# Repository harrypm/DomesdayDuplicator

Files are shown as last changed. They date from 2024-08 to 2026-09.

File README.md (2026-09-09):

# Domesday Duplicator (DdD)

Please see the [Project Wiki](https://github.com/harrypm/DomesdayDuplicator/wiki) for details of the project and for access to the project documentation.



The Domesday Duplicator is a LaserDisc capture focused, USB 3.0 based DAQ capable of 40 million samples per second acquisition of analogue RF data at 10-bits resolution, the data being in generic PCM style stream format is ready for real-time FLAC compression via capture apps.

Capturing is easy to use & inspect via the universal (hardware and platform support) [MISRC GUI](https://github.com/harrypm/MISRC-GUI)



# The Decode Family

The samples the DdD capture can be used with the family of decoders that make the FM RF Archival workflow ready to use today.

[LaserDisc Decode](https://github.com/happycube/ld-decode) / [VHS-Decode (Videotape)](https://github.com/oyvindln/vhs-decode/wiki/HiFi-Decode) / [HiFi Decode](https://github.com/oyvindln/vhs-decode/wiki/HiFi-Decode)

# 3D Printed Case 

The Domesday Duplicator also has a [3D models](https://github.com/simoninns/DomesdayDuplicator-Case) and ready to use data for producing 3D printed cases, to protect from dust or line with copper tape for affordable EMI shielding for example.

ddd-case

## Authors

Domesday Duplicator was written & designed by [Simon Inns](https://github.com/simoninns).

Current documentation & fabrication is maintained by [Harry Munday](https://github.com/harrypm). 

## Licences

- [Software License - (Creative Commons BY-SA 4.0)](https://github.com/simoninns/DomesdayDuplicator/blob/master/LICENSE)
- [Hardware License - (GPLv3)](https://creativecommons.org/licenses/by-sa/4.0/)

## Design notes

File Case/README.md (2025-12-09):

# Introduction

This repository contains a 3D printable case design for the Domesday Duplicator.

The case is designed using OpenSCAD and full source code is included.  There are also ready-made STL files for the various parts and materials if you don't want to build them yourself in OpenSCAD.

The case design contains multiple materials however you can easily remix the design using OpenSCAD customization GUI if you wish to print in a single material only (simply deselect the 'fill out text' and 'add logo' options and re-render).  Ready-made single material STL files are also included.



# Printing instructions

## Overview

The model has been printed and tested on the Prusa MK3S/MMU2S printer. All parts fit on a 20x20 printing bed.

The OpenSCAD source files provide a parameter interface that allows you to render either the whole model or the individual parts (ready for STL (or other 3D format) export).  This requires OpenSCAD 2019.05 or later.

## Recommended Print Settings

- Material: PLA Blue and PLA White
- Layer: 0.20mm (Quality)
- Infill: 15%
- Supports: None
- Notes: The upper and lower case parts simply snap together.  4x M3 6mm screws are required to hold the electronics in place.

## Print Time

Clearly this depends on your printer and it's settings.  For the 2 colour multi-material print the time was 11h 15m for both the upper and lower case.  For single-material printing to time was 8h 30m.

## Notes

The design also includes approximate renderings of the FPGA board, the DdD board and the USB3 board.  These are to assist with the design process and are not intended for printing.



# Author

The DomesdayDuplicator case is designed and maintained by Simon Inns.

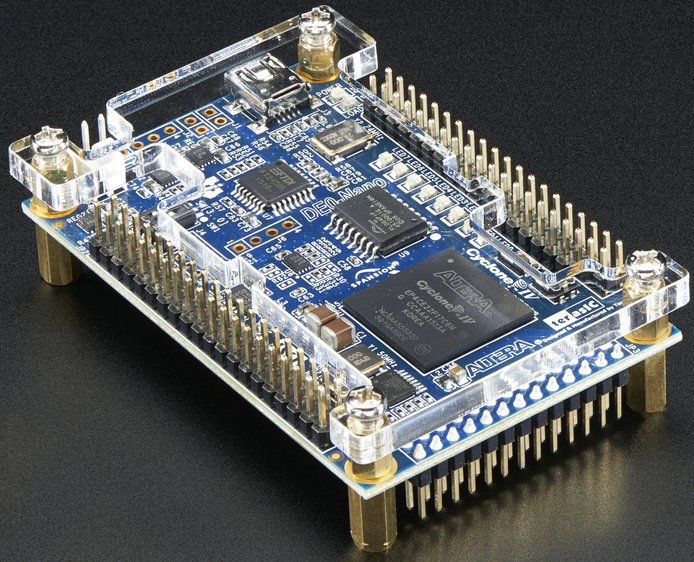
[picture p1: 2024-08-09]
assets/images/DE0.jpg

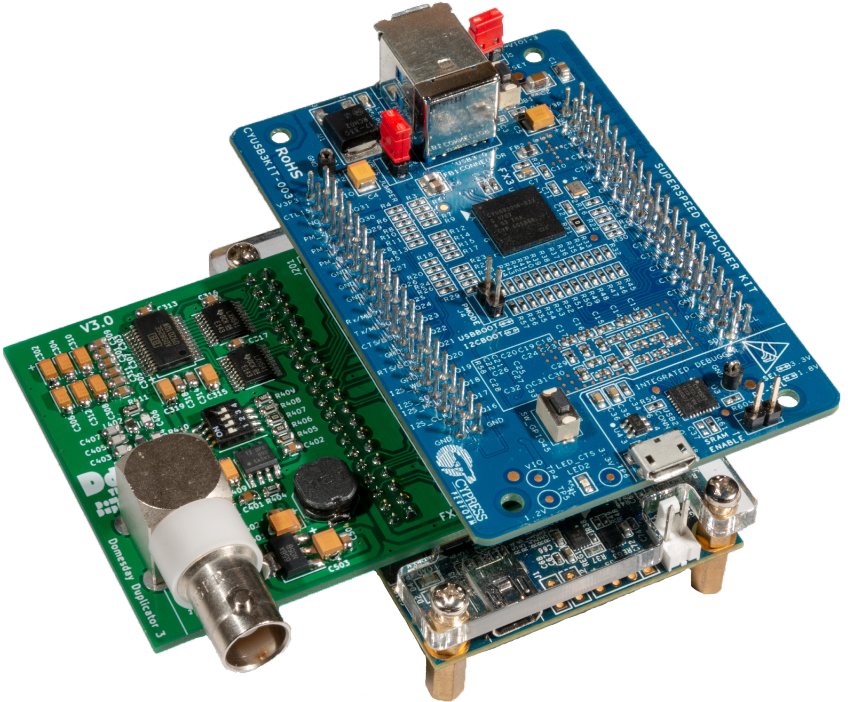
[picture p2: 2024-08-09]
assets/images/DdD-Green-PCB.png

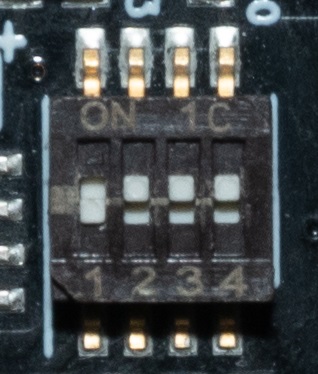
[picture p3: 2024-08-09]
assets/images/Gain_DIPS.jpg

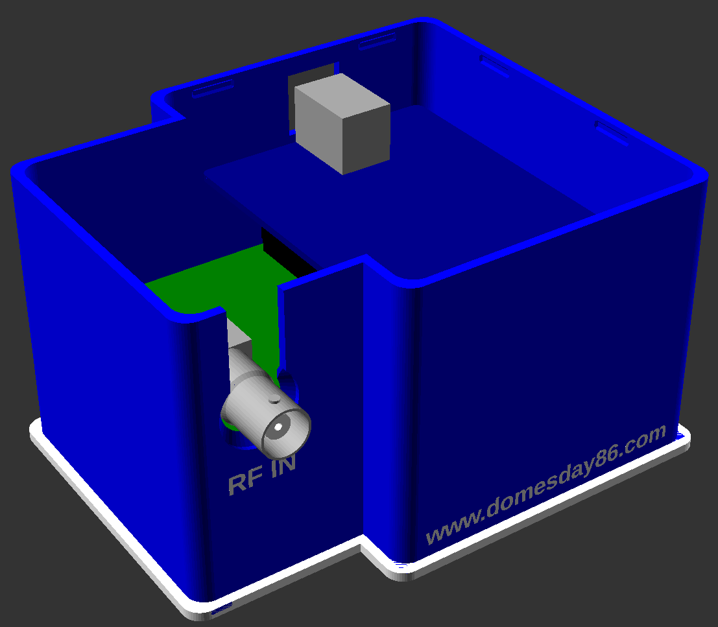
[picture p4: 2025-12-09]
Case/images/DdD-case2.png

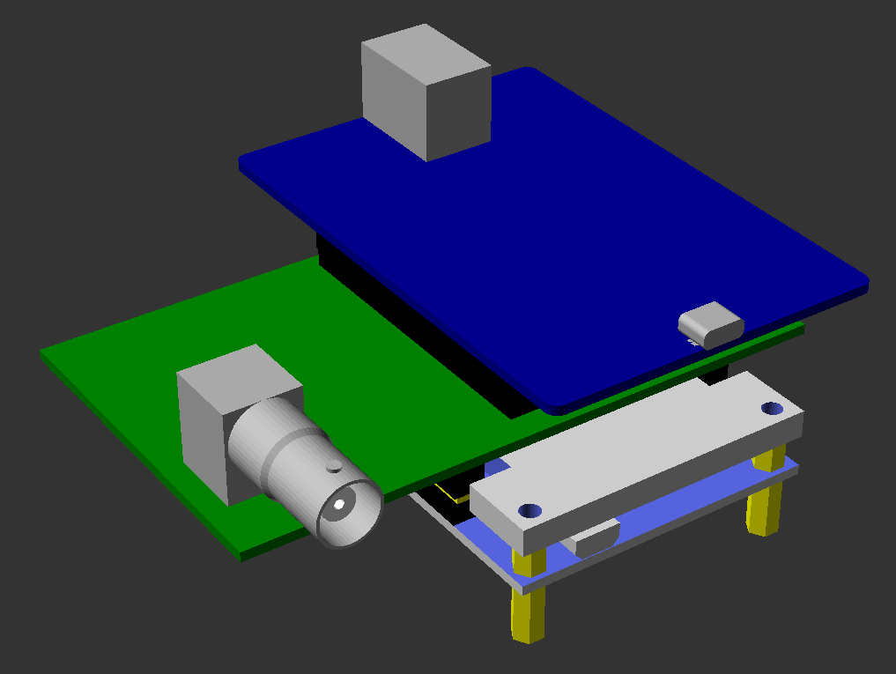
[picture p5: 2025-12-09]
Case/images/DdD-case3.png

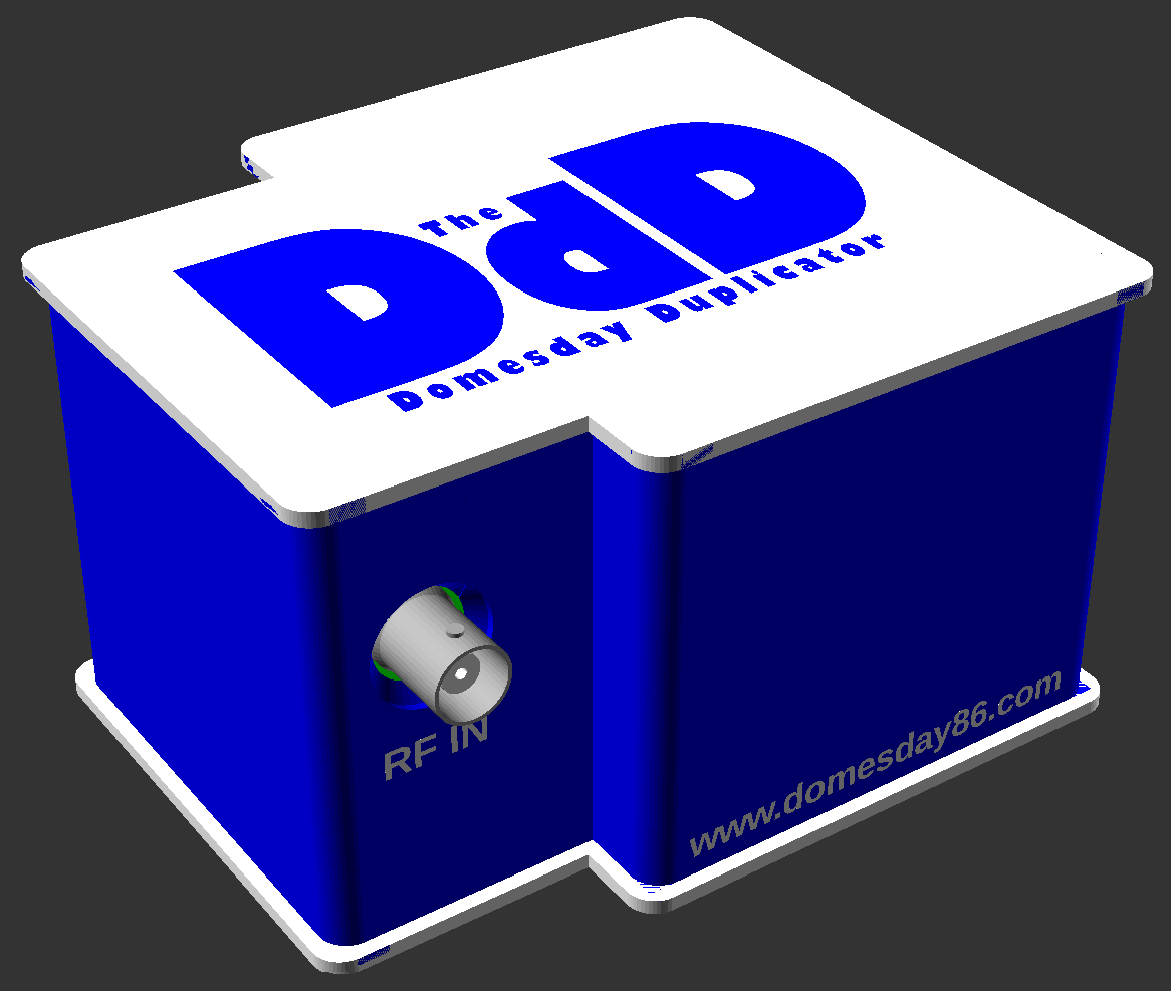
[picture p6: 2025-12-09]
Case/images/DdD-case1.png

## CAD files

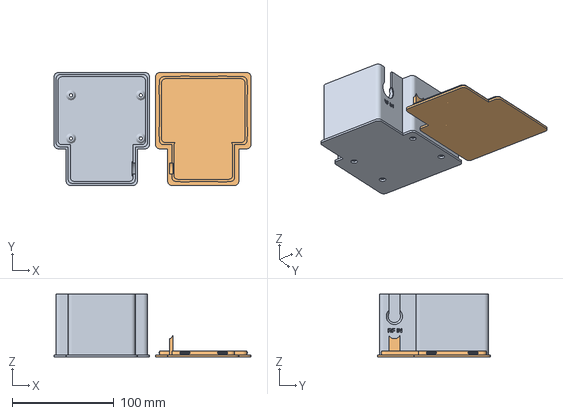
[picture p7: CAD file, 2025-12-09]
Case/3mf/multi_material.3mf
193.9 x 111.0 x 62.0 mm
base_material1.stl
top_material1.stl

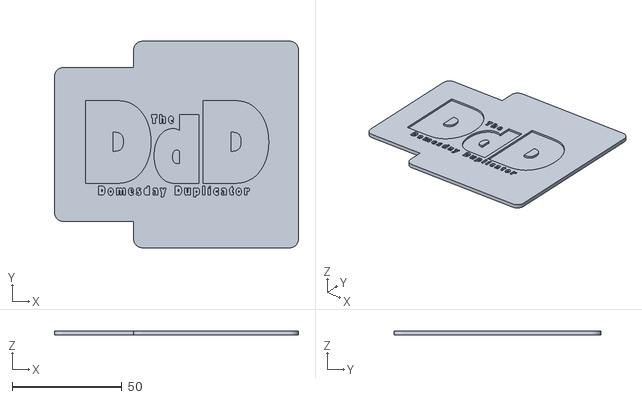
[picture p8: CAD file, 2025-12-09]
Case/stl/top_material1.stl
111.0 x 94.0 x 2.00

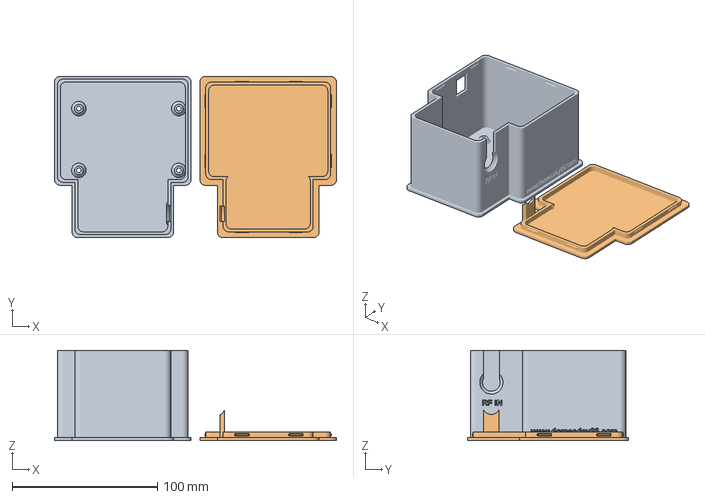
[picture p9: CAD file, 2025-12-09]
Case/3mf/single_material.3mf
194.0 x 111.1 x 62.0 mm
single_material_base.stl
single_material_top.stl

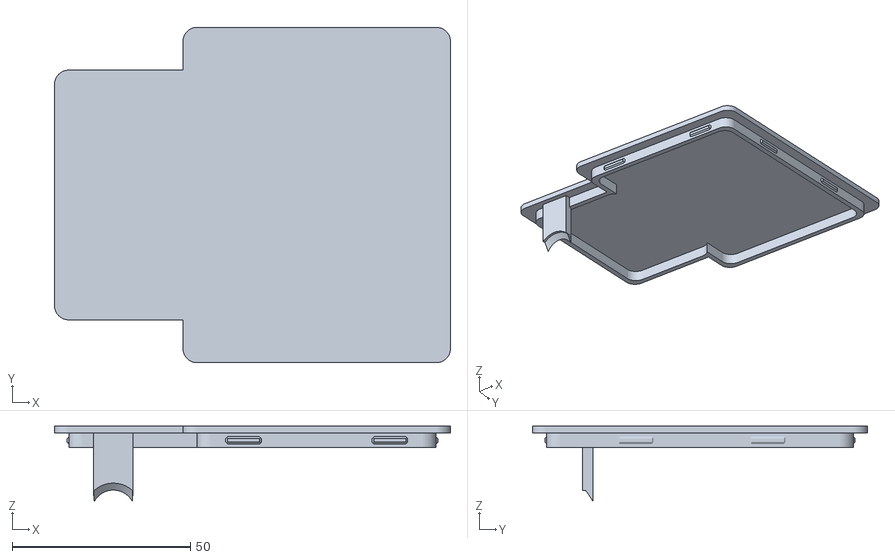
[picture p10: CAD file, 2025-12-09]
Case/stl/single_material_top.stl
111.0 x 94.0 x 21.0

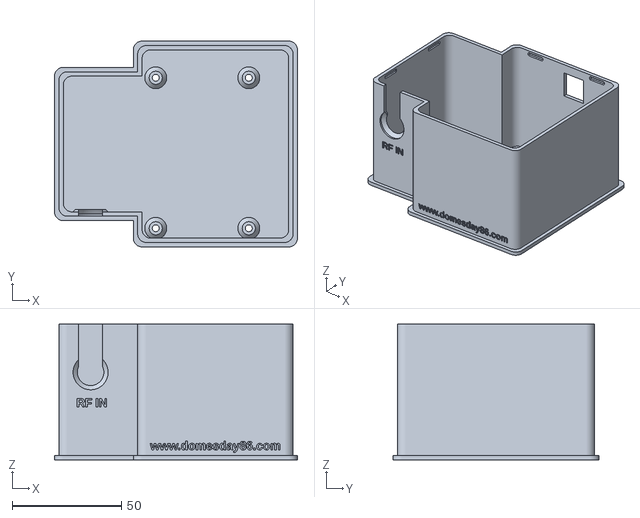
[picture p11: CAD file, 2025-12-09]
Case/stl/single_material_base.stl
111.0 x 94.0 x 62.0

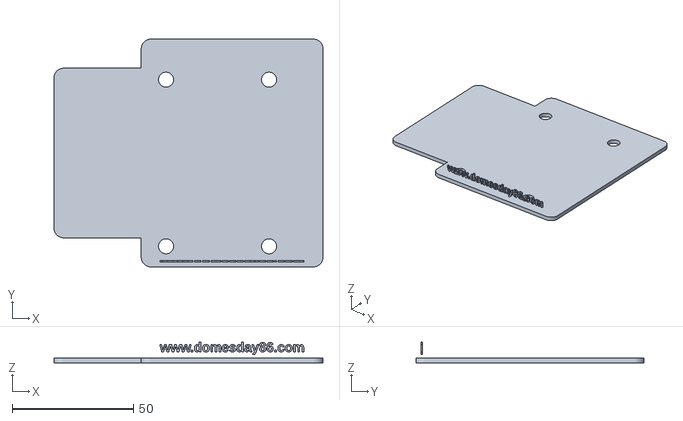
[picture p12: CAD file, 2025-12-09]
Case/stl/base_material1.stl
111.0 x 94.0 x 8.63

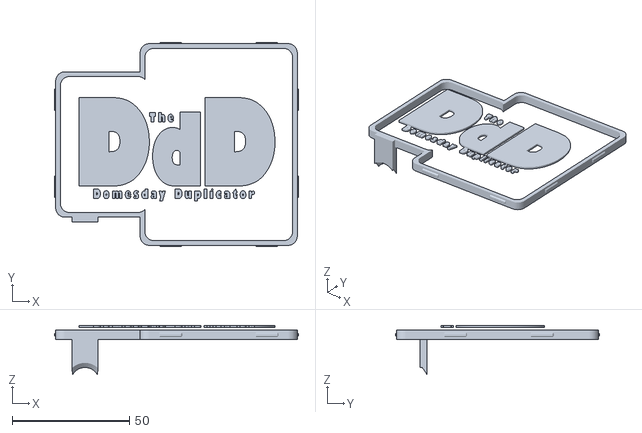
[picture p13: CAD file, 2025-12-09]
Case/stl/top_material2.stl
104.0 x 87.0 x 21.0

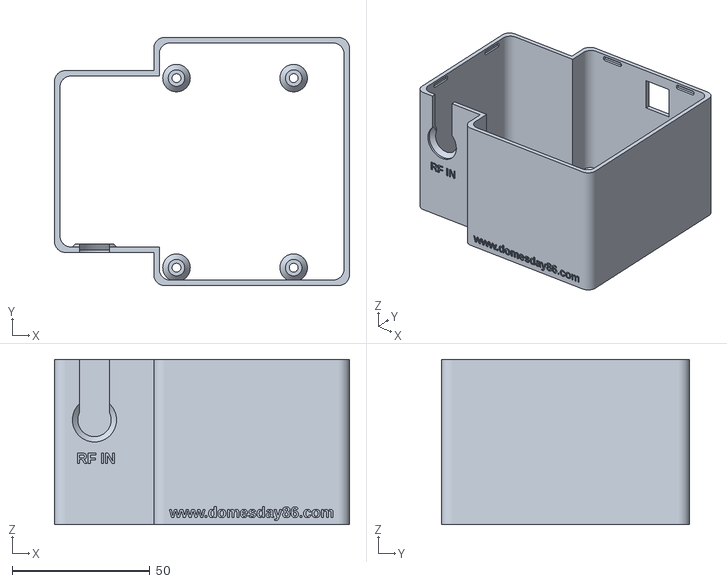
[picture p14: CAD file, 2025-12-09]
Case/stl/base_material2.stl
107.0 x 90.0 x 60.0

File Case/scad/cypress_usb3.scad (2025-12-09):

/************************************************************************

	cypress_usb3.scad
    
	Domesday Duplicator - 3D Printed Case
    Copyright (C) 2020 Simon Inns
	
    This file is part of Domesday Duplicator.
    
    This is free software: you can redistribute it and/or modify
	it under the terms of the GNU General Public License as published by
	the Free Software Foundation, either version 3 of the License, or
	(at your option) any later version.
    
    This program is distributed in the hope that it will be useful,
    but WITHOUT ANY WARRANTY; without even the implied warranty of
    MERCHANTABILITY or FITNESS FOR A PARTICULAR PURPOSE.  See the
    GNU General Public License for more details.
    
    You should have received a copy of the GNU General Public License
    along with this program.  If not, see <http://www.gnu.org/licenses/>.
	
    Email: simon.inns@gmail.com
    
************************************************************************/

include <BOSL/constants.scad>
use <BOSL/shapes.scad>
use <BOSL/transforms.scad>

// Draw the female header (7mm pins)
module usb3_female_header()
{
    color("black") cuboid([5,51,8], center = false);
}

// Draw the PCB
module usb3_pcb()
{
    color("darkblue") cuboid([56, 82.3, 1.6], center = false, fillet = 2, edges = EDGE_BK_RT+EDGE_BK_LF+EDGE_FR_RT+EDGE_FR_LF);
}

// Draw the USB3 connector
module usb3_usbheader()
{
    color("darkgrey") {
        move([(56 / 2) - 3.5,82.3 - 18,1.6]) cuboid([12,18,13], center = false);
    }

    color("blue") {
        move([(56 / 2) - 2,82.3 - 18 + 1,2.6]) cuboid([9,17.01,7], center = false);
        move([(56 / 2) - 0,82.3 - 18 + 1,2.6 + 7]) cuboid([5,17.01,4], center = false);
    }
}

// Draw the debug USB connector
module usb3_microheaader()
{
    color("darkgrey") {
        move([(56 / 2) - 3.5,-0.5,1.6]) cuboid([7,5.5,3], center = false, fillet = 1, edges = EDGE_TOP_LF+EDGE_TOP_RT+EDGE_BOT_LF+EDGE_BOT_RT);
    }
}

// Render the Cypress USB3 board
module render_usb3()
{
    move([0,0,0]) usb3_pcb();
    move([4.5,15,-8]) usb3_female_header();
    move([51 - 4.5,15,-8]) usb3_female_header();

    move([0,0,0]) usb3_usbheader();
    move([0,0,0]) usb3_microheaader();
}

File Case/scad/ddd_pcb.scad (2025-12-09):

/************************************************************************

	ddd_pcb.scad
    
	Domesday Duplicator - 3D Printed Case
    Copyright (C) 2020 Simon Inns
	
    This file is part of Domesday Duplicator.
    
    This is free software: you can redistribute it and/or modify
	it under the terms of the GNU General Public License as published by
	the Free Software Foundation, either version 3 of the License, or
	(at your option) any later version.
    
    This program is distributed in the hope that it will be useful,
    but WITHOUT ANY WARRANTY; without even the implied warranty of
    MERCHANTABILITY or FITNESS FOR A PARTICULAR PURPOSE.  See the
    GNU General Public License for more details.
    
    You should have received a copy of the GNU General Public License
    along with this program.  If not, see <http://www.gnu.org/licenses/>.
	
    Email: simon.inns@gmail.com
    
************************************************************************/

include <BOSL/constants.scad>
use <BOSL/shapes.scad>
use <BOSL/transforms.scad>

// Draw the BNC connector
module bnc_connector()
{
    // Rosenberger 51K204-400A5
    color("darkgrey") {
        difference() {
            union() {
                move([-6,0,0]) cuboid([12,12, 18.5 - 4], center = false);
                move([0,0,9]) rotate([90,0,0]) cyl(h=8.1, r=5.5, center = false);
                move([0,-8.1,9]) rotate([90,0,0]) cyl(h=1, r1=5.5, r2=5, center = false);
                move([0,-8.1,9]) rotate([90,0,0]) cyl(h=12.5, r=5, center = false);

                // Bayonet pins
                move([0,-17.1,3.5]) rotate([0,0,0]) cyl(h=11, r=1, center = false);
            }

            move([0,-8.2,9]) rotate([90,0,0]) cyl(h=12.5, r=4.5, center = false);
        }

        // Connection pins
        move([6 - 1,1,-4]) cyl(h=4, r=0.6, center = false);
        move([-6 + 1,1,-4]) cyl(h=4, r=0.6, center = false);

        move([6 - 1,10 + 1,-4]) cyl(h=4, r=0.6, center = false);
        move([-6 + 1,10 + 1,-4]) cyl(h=4, r=0.6, center = false);

        move([0,6,-4]) cyl(h=4, r=0.45, center = false);
    }

    color("white") {
        // Center part of BNC plug (for decoration)
        move([0,-8,9]) rotate([90,0,0]) tube(h=10, ir = 0.75, or=2.5, center = false);
    }
}

// Draw the PCB
module pcb()
{
    color("green") {
        move([0,-27,-1.6 / 2]) cuboid([95,57,1.6], center = false);
    }
}

// Draw a male pin header (7mm pins)
module male_header()
{
    color("black") cuboid([5,50,3], center = false);
    color("yellow") move([1,0.5,3]) cuboid([3,49,7], center = false);
}

// Draw a female pin header (7 mm pins)
module female_header()
{
    color("black") cuboid([5,51,8], center = false);
}

// Draw the headers
module headers()
{
    // Top headers
    move([45.5,-22.5,1.6 / 2]) male_header();
    move([87.5,-22.5,1.6 / 2]) male_header();

    // Bottom headers
    move([36,-22.75,-8.7]) female_header();
    move([79.5,-22.75,-8.7]) female_header();
}

// Render the DdD PCB and components
module render_ddd_pcb()
{
    move([9.6,-17.8,1.6 / 2]) bnc_connector();
    pcb();
    headers();
}

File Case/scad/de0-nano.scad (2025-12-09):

/************************************************************************

	de0-nano.scad
    
	Domesday Duplicator - 3D Printed Case
    Copyright (C) 2020 Simon Inns
	
    This file is part of Domesday Duplicator.
    
    This is free software: you can redistribute it and/or modify
	it under the terms of the GNU General Public License as published by
	the Free Software Foundation, either version 3 of the License, or
	(at your option) any later version.
    
    This program is distributed in the hope that it will be useful,
    but WITHOUT ANY WARRANTY; without even the implied warranty of
    MERCHANTABILITY or FITNESS FOR A PARTICULAR PURPOSE.  See the
    GNU General Public License for more details.
    
    You should have received a copy of the GNU General Public License
    along with this program.  If not, see <http://www.gnu.org/licenses/>.
	
    Email: simon.inns@gmail.com
    
************************************************************************/

include <BOSL/constants.scad>
use <BOSL/shapes.scad>
use <BOSL/transforms.scad>

// Draw a male pin header (7mm pins)
module male_nano_header()
{
    color("black") cuboid([5,50,3], center = false);
    color("yellow") move([1,0.5,3]) cuboid([3,49,7], center = false);
}

// Draw the DE0-Nano FPG board
module render_de0_nano()
{
    move([0,-75.18,0]) {
        difference() {
            cuboid([49.02, 75.18, 11], center = false);

            // Seperate PCB and case
            move([-0.5,-0.5,1.6]) cuboid([50, 76, 5], center = false);

            // Screw holes
            move([3.3, 3.05, 5.5]) cyl(h=13, r = 1.6);
            move([45.72, 3.05, 5.5]) cyl(h=13, r = 1.6);

            move([3.3, 71.88, 5.5]) cyl(h=13, r = 1.6);
            move([45.72, 71.88, 5.5]) cyl(h=13, r = 1.6);

            // Cutouts for header pins
            move ([-0.01,12.5,1.6]) cuboid([7, 57, 11], center = false);
            move ([45.72 - 3.7 + 0.01,12.5,1.6]) cuboid([7, 57, 11], center = false);

            // Cutout for mini USB connector
        }
    }

    // Header pin rows
    move([0,-75.18 + 16.26,1.6]) male_nano_header();
    move([49.02 - 5,-75.18 + 16.26,1.6]) male_nano_header();

    color("yellow") move([0,-75.18,0]) {
        // Standoffs
        $fn = 6;
        move([3.3, 3.05, -5]) cyl(h=10, r = 2.5);
        move([45.72, 3.05, -5]) cyl(h=10, r = 2.5);

        move([3.3, 71.88, -5]) cyl(h=10, r = 2.5);
        move([45.72, 71.88, -5]) cyl(h=10, r = 2.5);
    }

    color("yellow") move([0,-75.18,9]) {
        // Standoffs
        $fn = 6;
        move([3.3, 3.05, -5]) cyl(h=5.4, r = 2.5);
        move([45.72, 3.05, -5]) cyl(h=5.4, r = 2.5);

        move([3.3, 71.88, -5]) cyl(h=5.4, r = 2.5);
        move([45.72, 71.88, -5]) cyl(h=5.4, r = 2.5);
    }

    // USB mini connector
    move([9,-75,1.6]) cuboid([7.5,9,3.5], center = false, chamfer = 1.2, edges = EDGE_BOT_LF+EDGE_BOT_RT);
}

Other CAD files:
Case/scad/lower_case.scad
Case/scad/main.scad
Case/scad/material.scad
Case/scad/upper_case.scad

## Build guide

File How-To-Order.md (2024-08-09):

# DomesDay Duplicator

The DdD is a plug-and-play RF capture tool 40msps 10-bit ADS825 ADC & OPA690 amp with a simple capture & control GUI.

Software is built maily for Linux but MacOS is supported alongside Windows support.

# The PCB

Today we have a PCBway shared project that handles all the tehcnical details allowing anyone to have the DdD main PCB fabraicted populated with parts soldered and shipped to them directly at cost with no markup.

`Cost: 90-125USD` (Relative to infaltion & shipping)

`Total Cost: 290-330USD` (upto 350USD if DE0 price is high)

## Step 1

Firstly aquire the 2 off-shelf development boards.

Please do look around, local venders can be cheeper and you can also get these boards a fair bit more cheeper if your with a educational institution or work for one.

[FX3 - Digikey](https://www.digikey.com/en/products/detail/infineon-technologies/CYUSB3KIT-003/4989179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)

`KIT DEV EZ-USB FX3 USB3.0
428-3347-ND‎
‎CYUSB3KIT-003‎
Cypress Semiconductor Corp`

[DE0 - Digikey](https://www.digikey.com/en/products/detail/terasic-inc/P0082/2625112)

`DE0-NANO EVAL BOARD
‎P0082-ND‎
‎P0082‎
Terasic Inc.`

> [!TIP]  
> - FX3 comes with a USB 3.0 Type-B to Type-A cable.
> - DE0 comes with a USB 2.0 Mini to Type-A cable.

##  Step 2

Go to [PCBway Shared Project](https://www.pcbway.com/project/shareproject/DoomsDayDuplicator_Rev_3.html)

Select `PCB+Assembly`

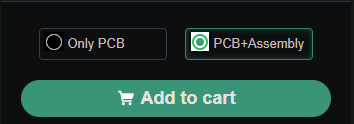
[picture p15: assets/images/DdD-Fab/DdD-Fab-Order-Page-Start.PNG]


## Step 3

You will see a order page pop up.

- Selection box 2 (highlighted in RED) should have quantity set to 1 to build a single complete DdD PCB.
- You can change the base PCB colour with changing `solder mask` and text colour with `silkscreen` excluding the UV process options; these have no effect on cost or fabrication.

> [!NOTE]  
> You will have 4 spare extra PCBs with your order, as the mimium you can order is 5 PCBs. 

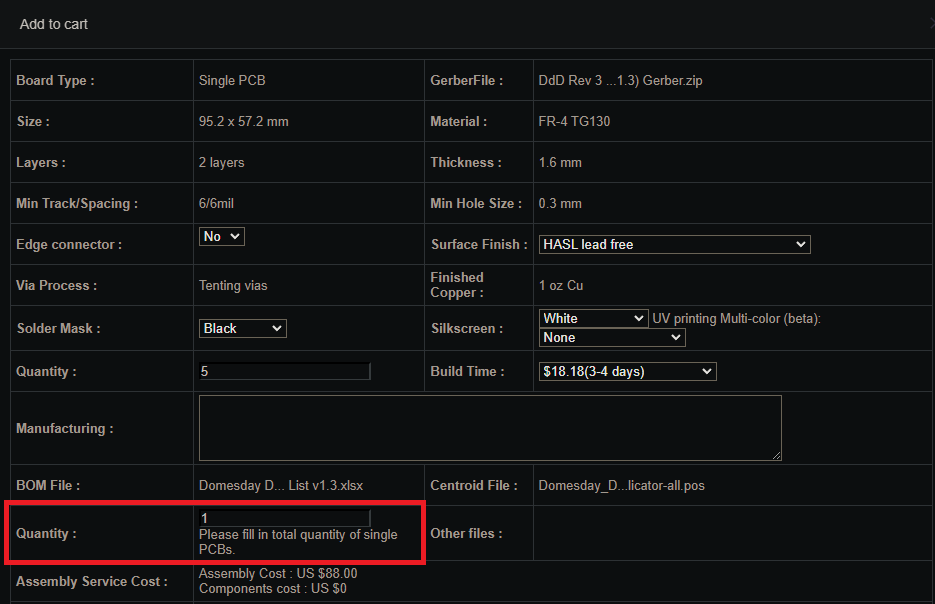
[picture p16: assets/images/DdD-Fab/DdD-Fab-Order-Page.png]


## Step 4

Wait for parts quote and email conformation.

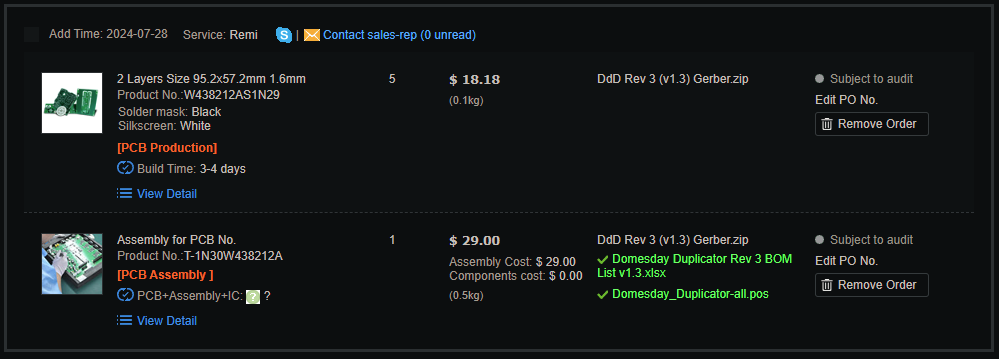
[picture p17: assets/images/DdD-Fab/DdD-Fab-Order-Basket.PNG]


## Step 5

> [!WARNING]  
> You may encounter a couple issues these will be via email.

- If asked how many layers the PCB is say 2.

- If issue with SRN8040-101M on pad L501, and asked to solder manually say yes, as the part will solder just fine and is for power filtering it's non-critical as long as its got soldered contact that's fine.

- If issues with silkscreen solder bridges tell them to proceed anyways when emailed, as any standard colour change will work just fine and not affect soldering of parts.

Before the PCB has final soldering done and is shipped form PCBway you will get a email with a photo, ensure this looks idential to this image below in terms of parts colour/placement. 



## Step 6

There is 2 2.54mm Headder pins on the DdD PCB that need to be cut flush. 

Marked with RED boxes



This allows the FX3 to fit properly with its blanked out pin slots.

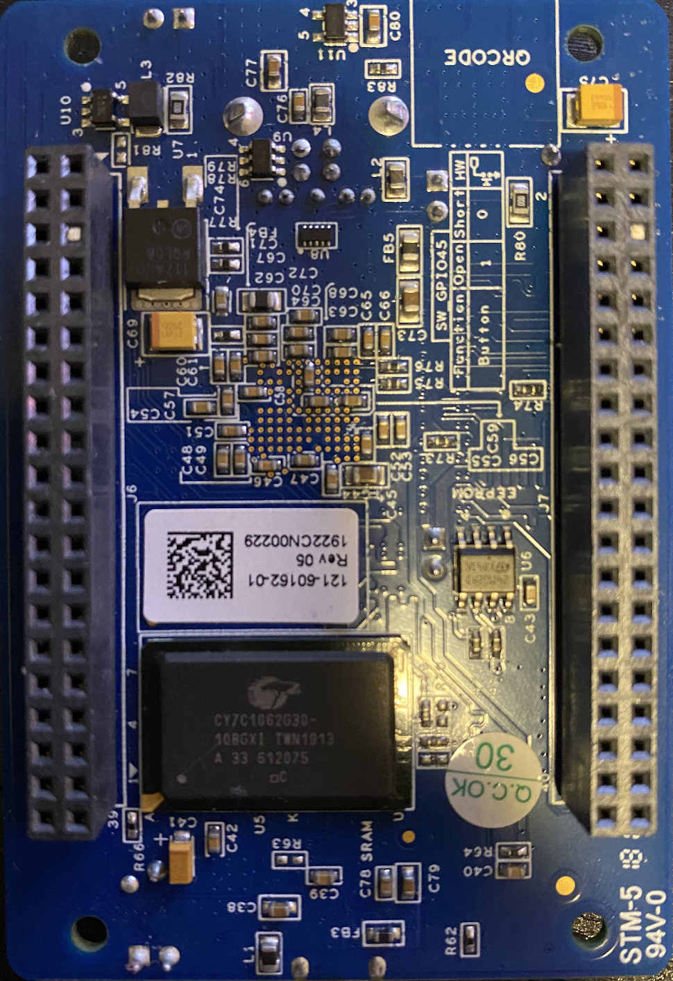
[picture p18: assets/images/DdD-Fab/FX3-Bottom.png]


# User Final Assembly 

**Don't assemble the board yet! First, you'll have to get it flashed - no worries, it's really simple.**

- [Windows 10/11 Firmware Flashing Package v2.0](https://drive.google.com/open?id=1uIFqS8PBPw7L4DWuKVc2dPEI4tBV-r3Q&authuser=harry%40opcomedia.com&usp=drive_fs)

The flashing software can be done inside Windows or Linux. 

## Push all PCBs together

Ensure the correct orientation of PCBS and push them together after flashing.

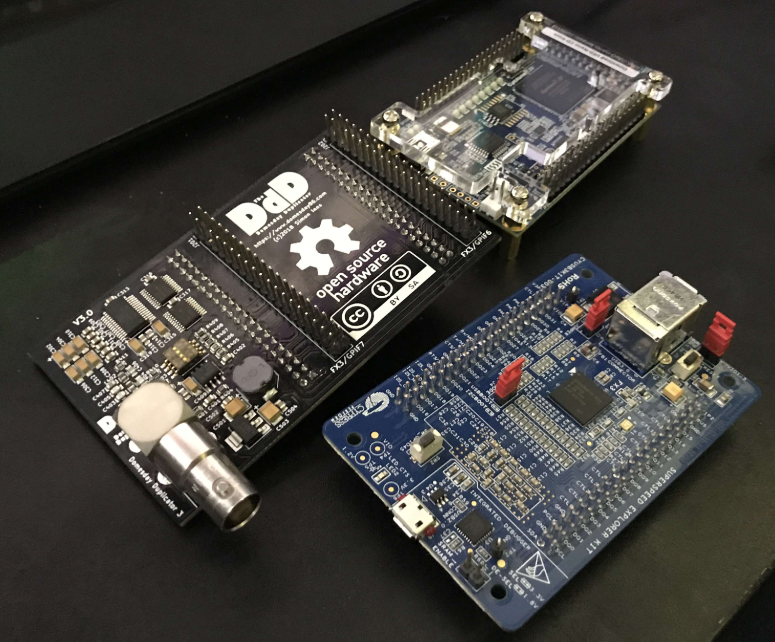
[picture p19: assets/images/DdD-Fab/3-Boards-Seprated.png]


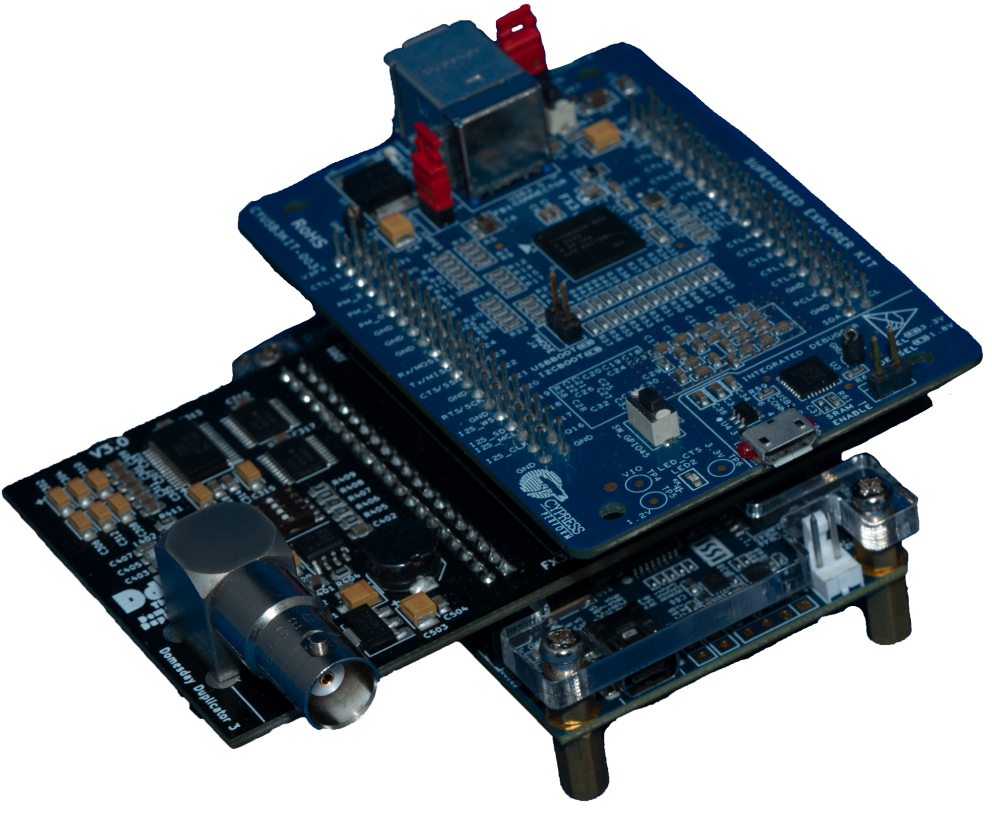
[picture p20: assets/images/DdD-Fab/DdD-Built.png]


# Conformal Coating

PCBWay charges $100, and it costs $15 for a small jar. I'd recommend picking up some MG Chemicals 422C off amazon or whatever vendor stocks it in your region.

It only takes a few minutes to do a fine coat on the legs of the components.

To quickly dry its surface lift the board on some tin foil balls on a tray at 50°C in a fan oven to set the coating and let fully harden over 48 hours or let it air dry in a clean environment.

I note this for protecting your PCB from dust and contaminatse like hair strands and finger oils.

# 3D Printable Case

The DdD is not immune from stray RF and EMI, a shielded case is ideal to prevent this.

M3 Nuts / Bolts and a screwdriver bit or allen key are required, along with copper tape for shield lining.

You can find SLT files in the `03 3D-Case` folder of this repository.

# Page End

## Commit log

2023-02-19 Update for current usage and install.
2025-12-09 add case to master
    [base_material1.stl, base_material2.stl, cypress_usb3.scad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]
2026-06-04 Fix workflow packaging robustness and runner compatibility
    Handle optional downsampling README copies in packaging steps, switch macOS x64 to macos-15-intel, and add onecoreuap compatibility import fallback on Windows CI.
